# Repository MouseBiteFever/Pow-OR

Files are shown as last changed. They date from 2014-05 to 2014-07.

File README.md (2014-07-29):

Pow-OR
======

Power multiplexer

This will be a repository for the Eagle CAD design files of the Pow-OR power multiplexer board.
<br>To follow development of the board please go to http://MouseBiteFever.tumblr.com
<br><br>
A few video demonstrations of the Pow-OR board on can be foud on youtube at http://www.youtube.com/channel/UCmLNvzKj7SQ2D3ENkpwOFEA
<br><br>
I have put a small number of these up for sale on Tindie, and I just added 10 more as of 7/28/14. I'll be updating the stock as I get chips in and assemble boards.<br>
https://www.tindie.com/products/MouseBiteFever/pow-or-v131/
<br><br>

<br />This work is licensed under a <a rel="license" href="http://creativecommons.org/licenses/by-sa/4.0/">Creative Commons Attribution-ShareAlike 4.0 International License</a>.

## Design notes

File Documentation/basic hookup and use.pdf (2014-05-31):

## Pow-OR Basic Hookup and Usage Guide

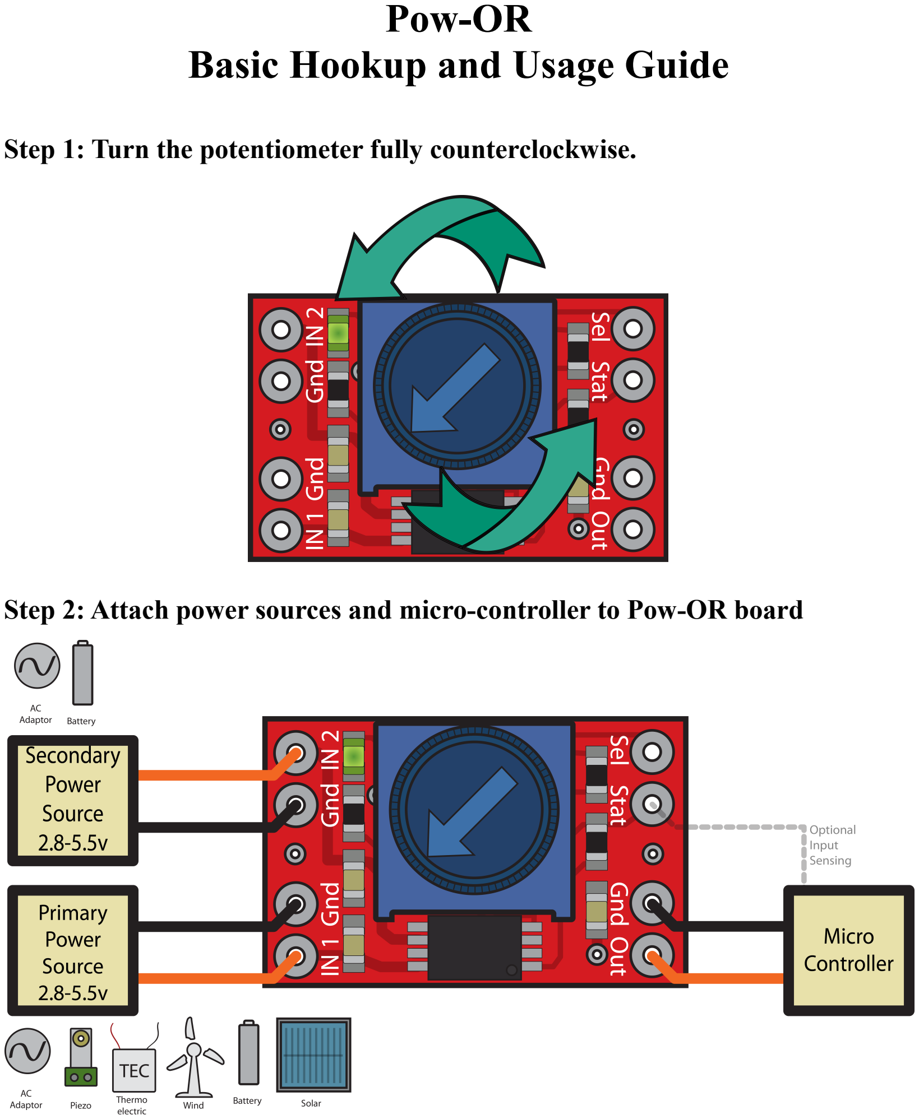
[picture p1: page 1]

Step 1: Turn the potentiometer fully counterclockwise.
Step 2: Attach power sources and micro-controller to Pow-OR board

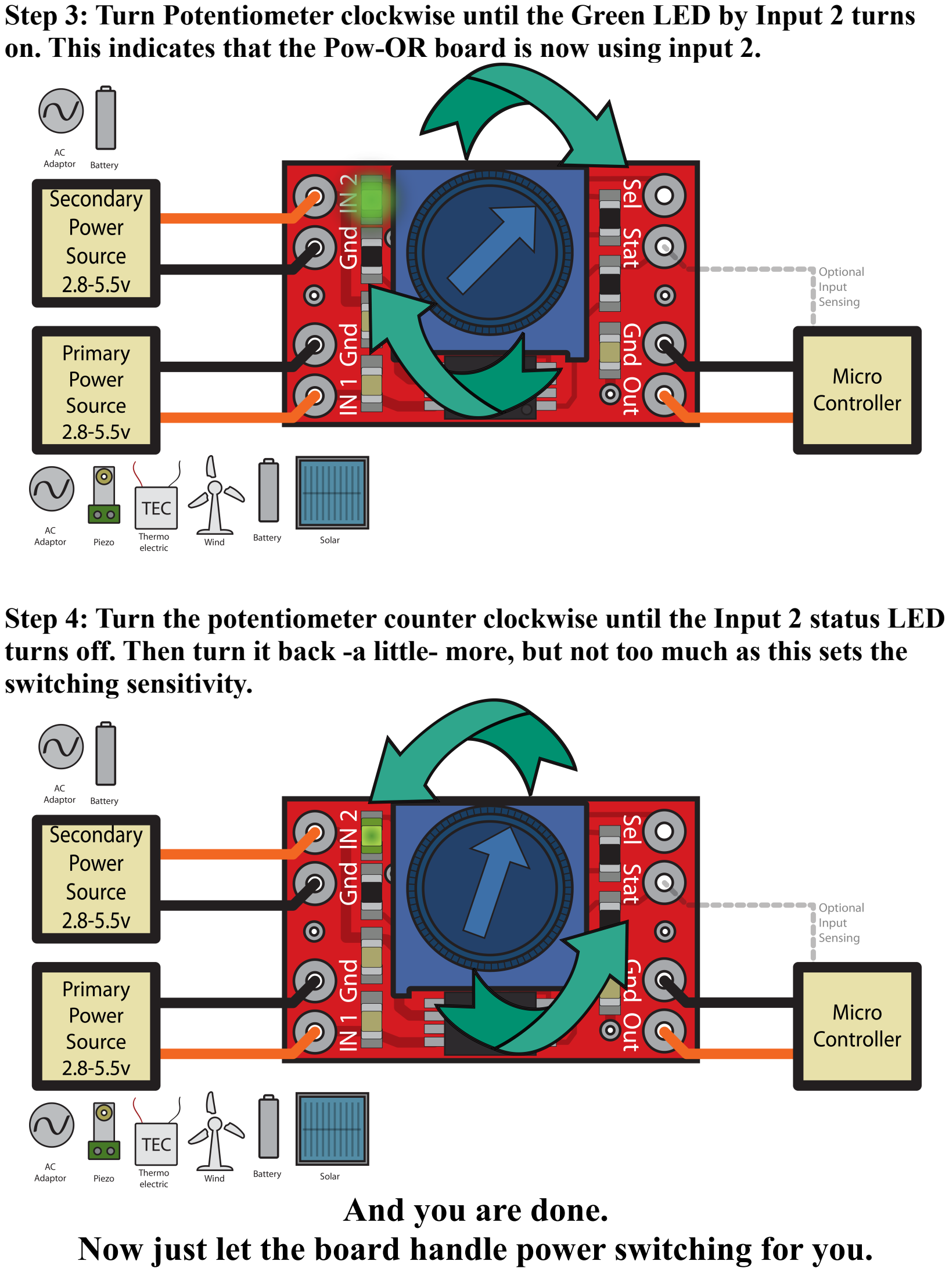
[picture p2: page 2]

Step 3: Turn Potentiometer clockwise until the Green LED by Input 2 turns on. This indicates that the Pow-OR board is now using input 2.
Step 4: Turn the potentiometer counter clockwise until the Input 2 status LED turns off. Then turn it back -a little- more, but not too much as this sets the switching sensitivity.

And you are done.
Now just let the board handle power switching for you.

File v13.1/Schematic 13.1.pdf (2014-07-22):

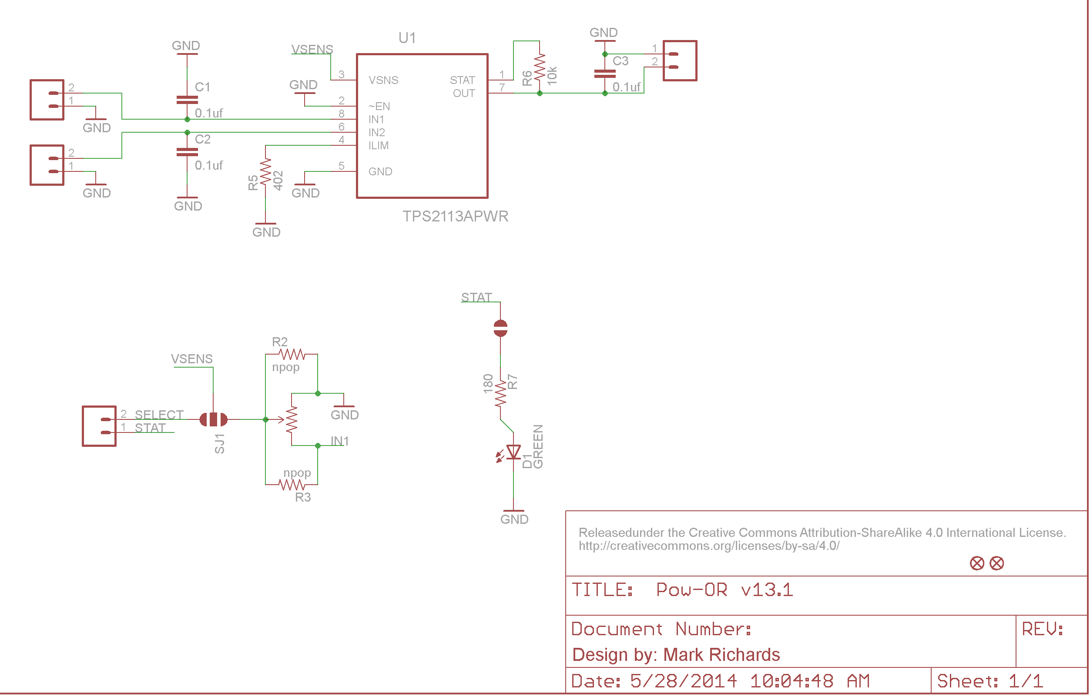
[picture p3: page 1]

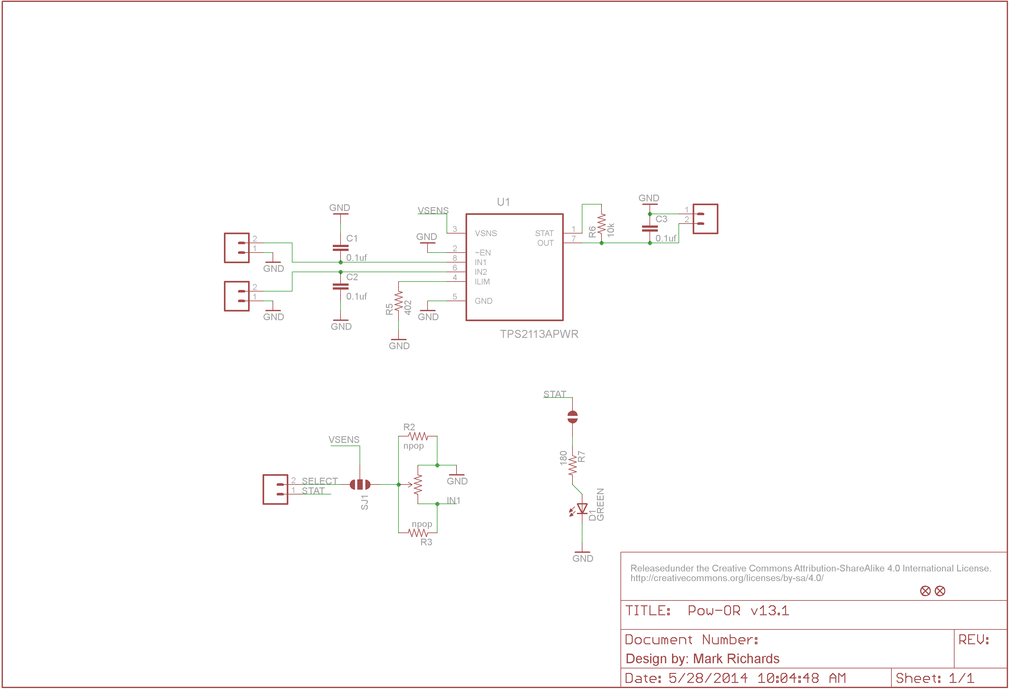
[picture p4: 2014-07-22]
v13.1/Schematic 13.1.png

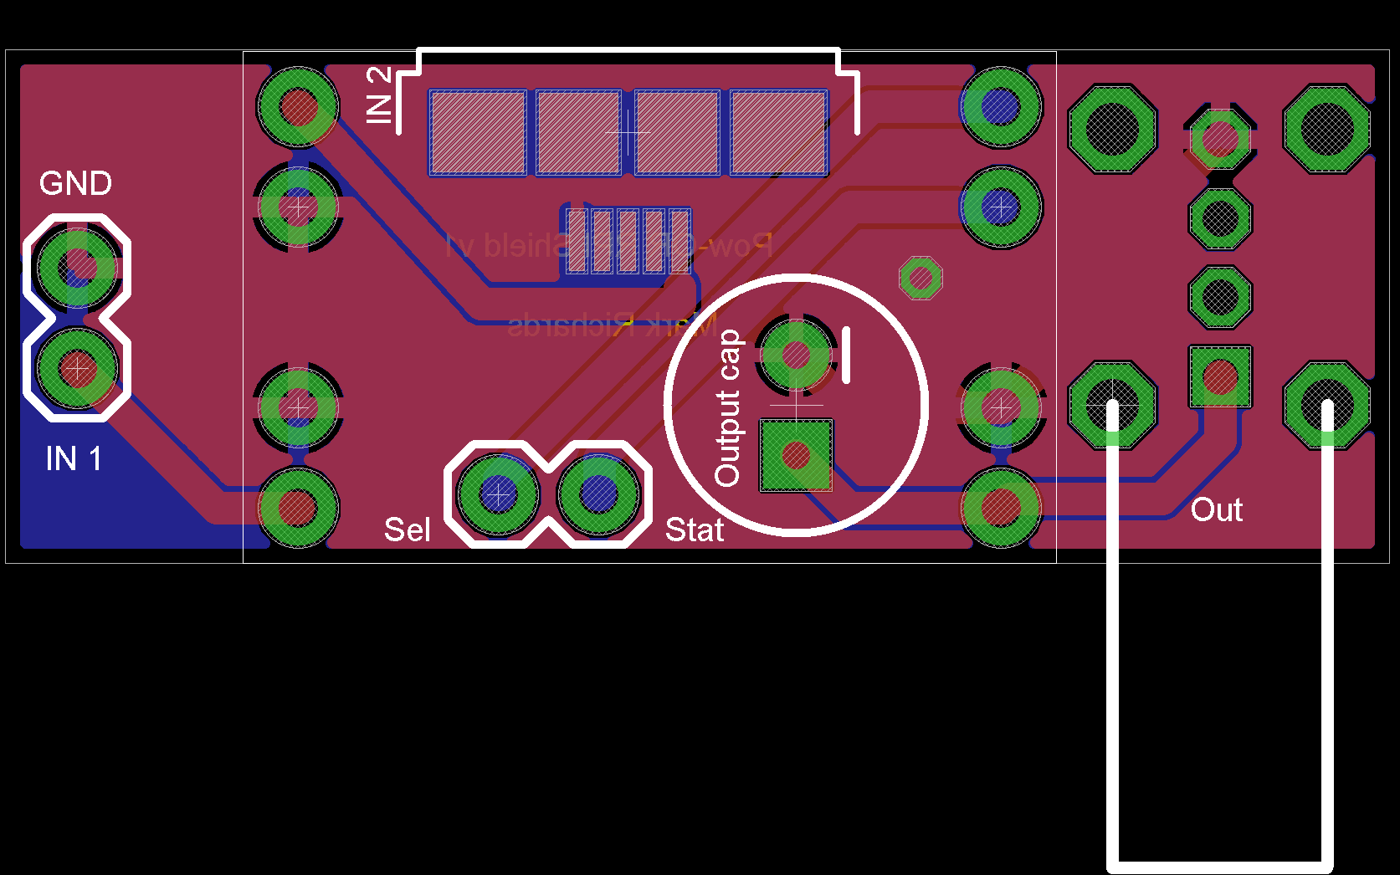
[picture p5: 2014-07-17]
RPI shield/v1.png

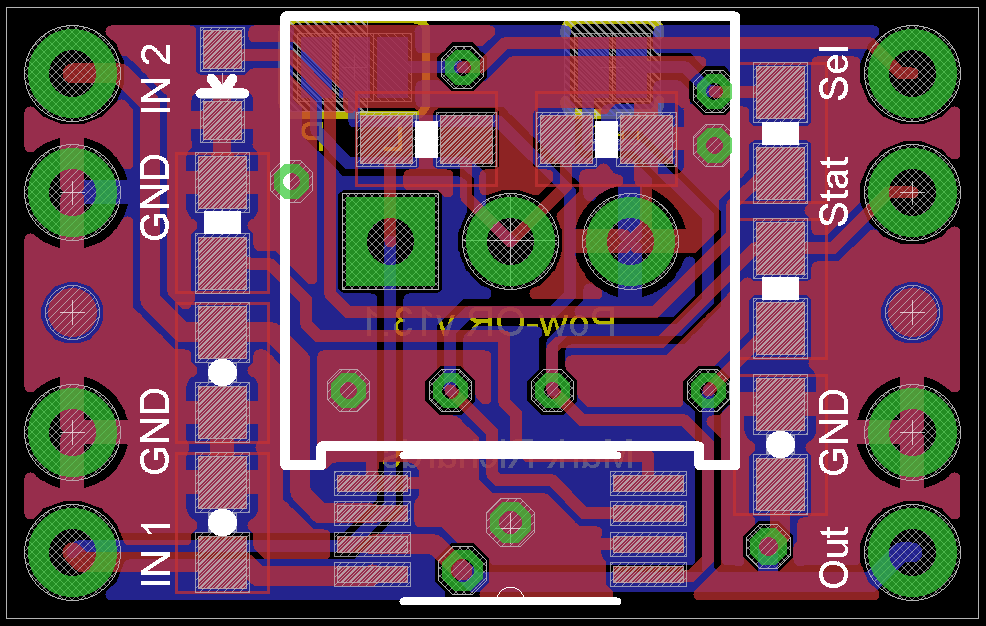
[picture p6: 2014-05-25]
v13.1/v13.1.png

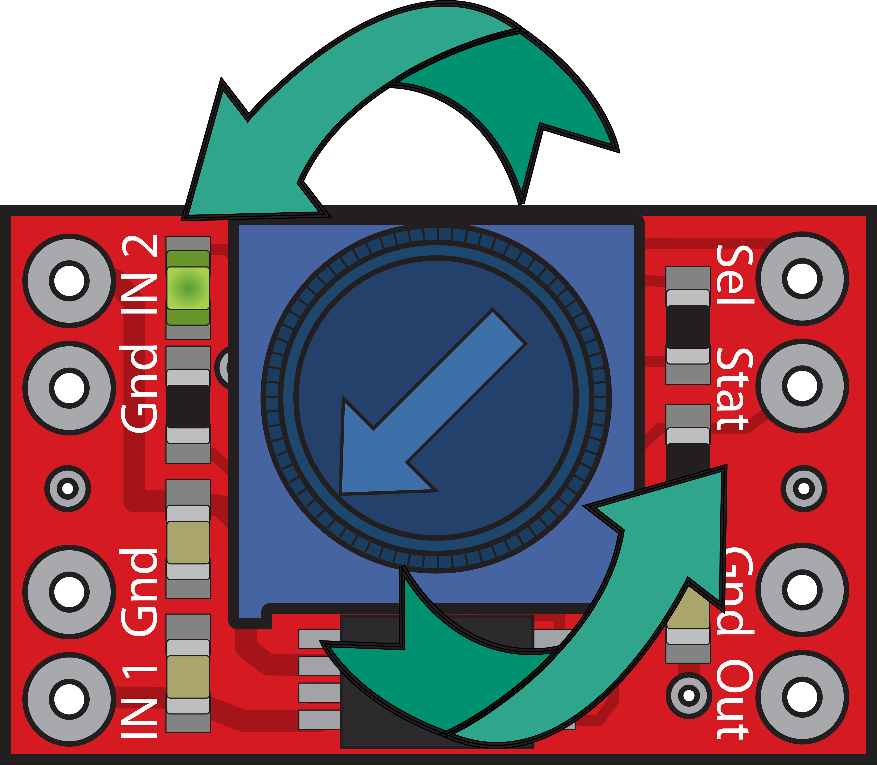
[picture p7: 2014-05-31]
Documentation/counterclockwise1.png

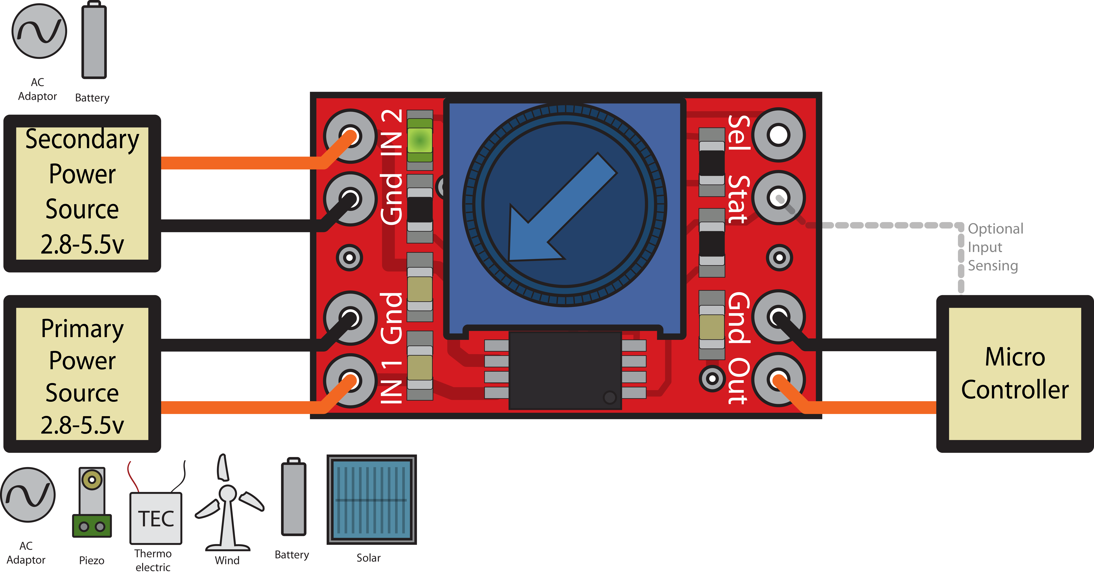
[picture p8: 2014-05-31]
Documentation/hookup.png

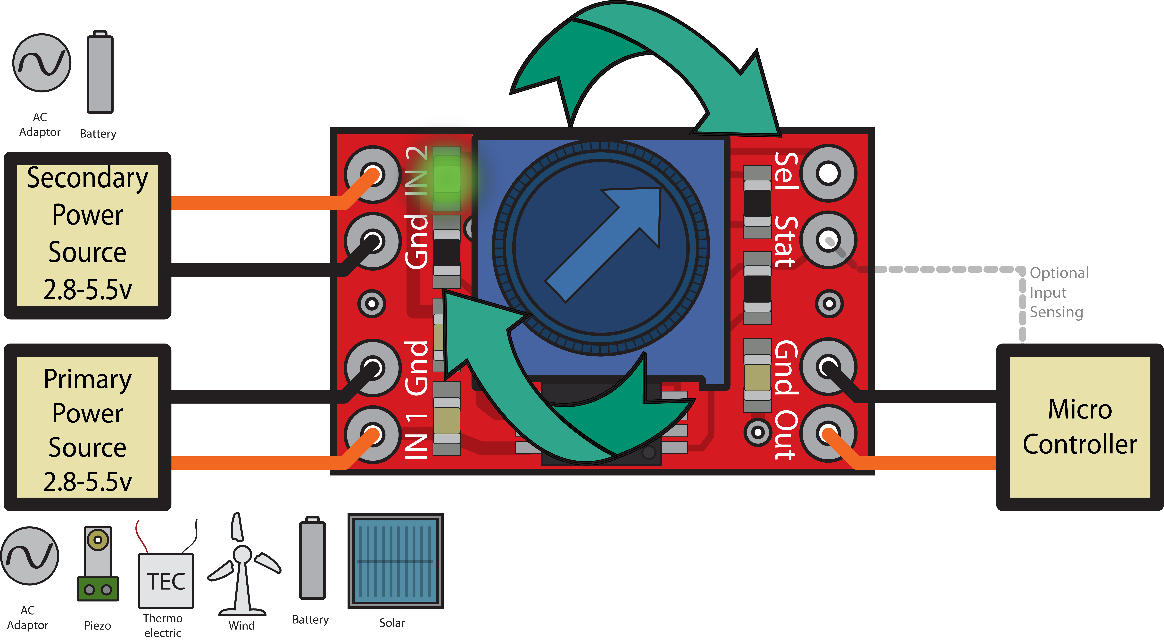
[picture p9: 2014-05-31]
Documentation/clockwise.png

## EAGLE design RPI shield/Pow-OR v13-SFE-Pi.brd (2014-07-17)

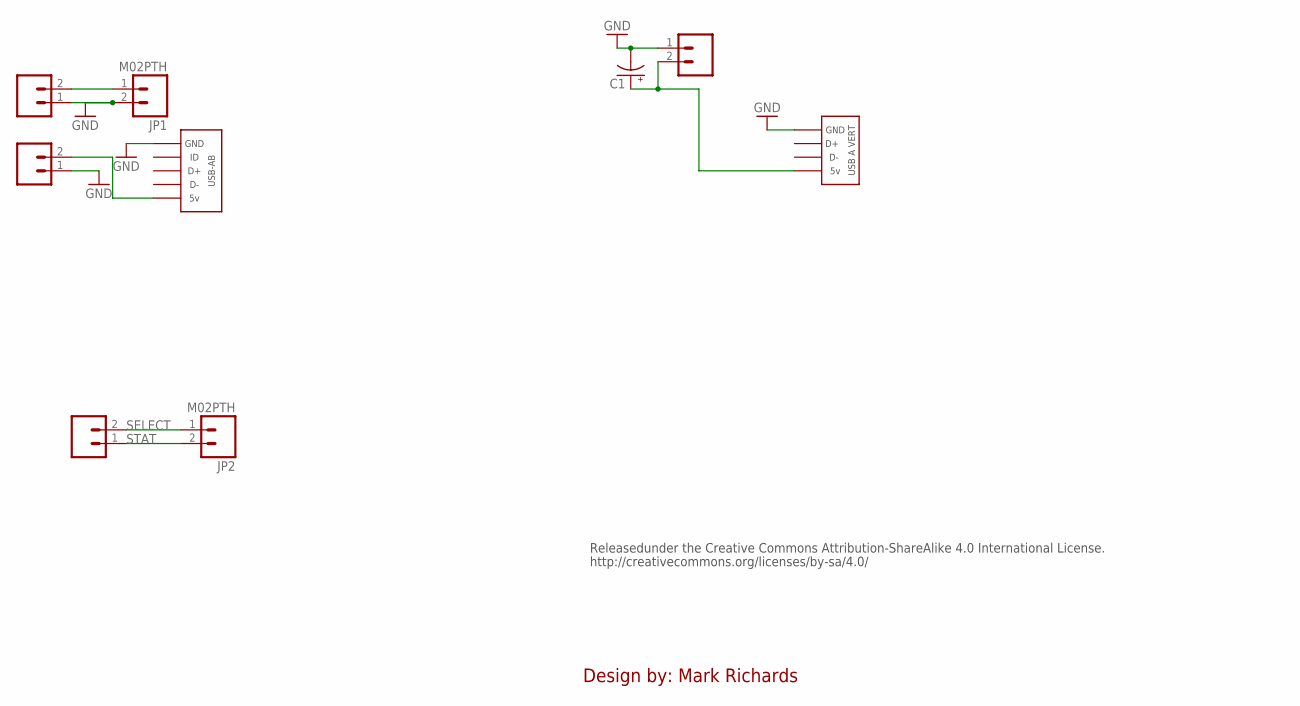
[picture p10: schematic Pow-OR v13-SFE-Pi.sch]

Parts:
C1: CAP_POLPTH1; CPOL-RADIAL-100UF-25V
JP1, JP2: M02PTH; 1X02
JP3, JP4, JP5, JP6: M021X02_NO_SILK; 1X02_NO_SILK
U$1: USB-AB
U$2: USBA-VERT

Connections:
GND: C1.2 (-), JP1.2, JP3.1, JP4.1, JP6.1, U$1.G, U$2.NEG (GND)
IN1: JP1.1, JP3.2
unnamed: JP4.2, U$1.V
OUT: C1.1 (+), JP6.2, U$2.VCC
SELECT: JP2.1, JP5.2
STAT: JP2.2, JP5.1

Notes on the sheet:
Releasedunder the Creative Commons Attribution-ShareAlike 4.0 International License.
http://creativecommons.org/licenses/by-sa/4.0/
Design by: Mark Richards

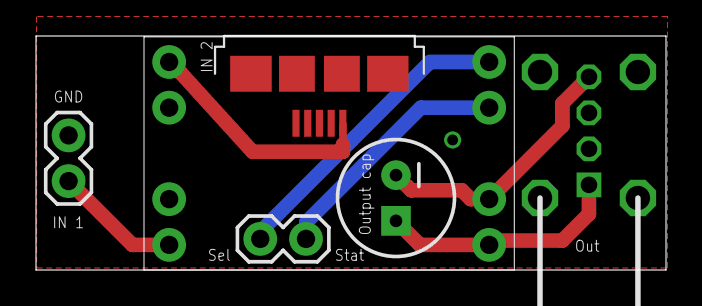
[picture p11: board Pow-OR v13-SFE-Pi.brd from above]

Board: 2 copper layers, 35.0 x 13.0 mm, 9 parts (0 on the bottom side), 6 nets.

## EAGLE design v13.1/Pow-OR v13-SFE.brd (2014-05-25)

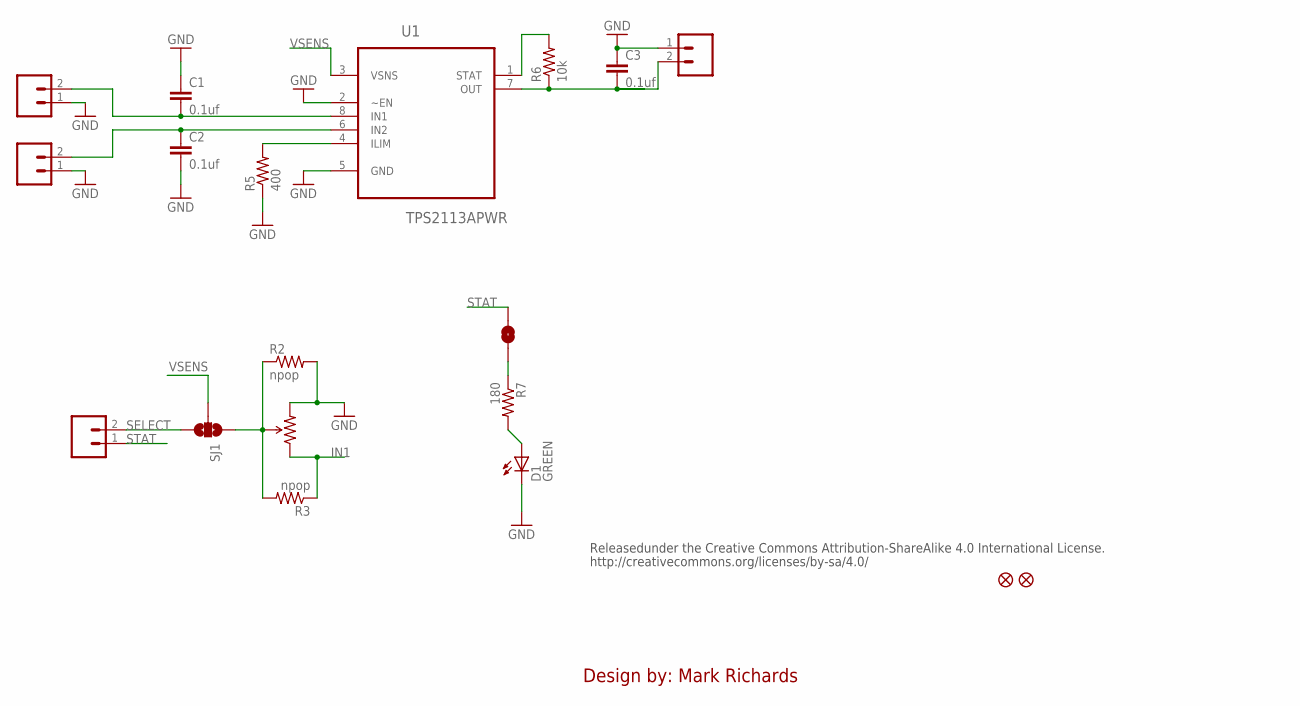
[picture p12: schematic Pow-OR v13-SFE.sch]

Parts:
C1, C2, C3: 0.1uf; 0603-CAP
D1: GREEN; LED-0603
FID1, FID2: FIDUCIAL1X2; FIDUCIAL-1X2
JP3, JP4, JP5, JP6: M021X02_NO_SILK; 1X02_NO_SILK
R1: TRIMPOT-PTH-KNOB; 3386U
R2, R3: npop; 0603-RES
R5: 400; 0603-RES
R6: 10k; 0603-RES
R7: 180; 0603-RES
SJ1: SOLDERJUMPER_2WAYPASTE1&2; SJ_3_PASTE1&2
SJ2: SOLDERJUMPERNC2; SJ_2S-NOTRACE
U1: TPS2113APWR; SOP65P640X120-8N

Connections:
GND: C1.1, C2.2, C3.1, D1.C, JP3.1, JP4.1, JP6.1, R1.3 (CW), R2.2, R5.1, U1.2 (~EN), U1.5 (GND)
ILIM: R5.2, U1.4 (ILIM)
IN1: C1.2, JP3.2, R1.1 (CCW), R3.1, U1.8 (IN1)
IN2: C2.1, JP4.2, U1.6 (IN2)
unnamed: D1.A, R7.2
unnamed: R1.2 (WIPER), R2.1, R3.2, SJ1.1
unnamed: R7.1, SJ2.1
OUT: C3.2, JP6.2, R6.1, U1.7 (OUT)
SELECT: JP5.2, SJ1.3
STAT: JP5.1, R6.2, SJ2.2, U1.1 (STAT)
VSENS: SJ1.2, U1.3 (VSNS)

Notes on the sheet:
Releasedunder the Creative Commons Attribution-ShareAlike 4.0 International License.
http://creativecommons.org/licenses/by-sa/4.0/
Design by: Mark Richards

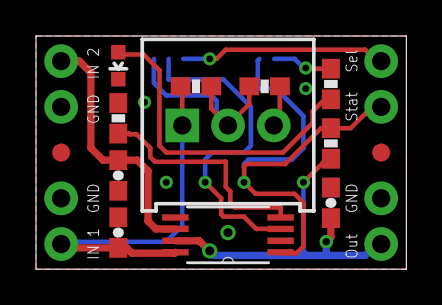
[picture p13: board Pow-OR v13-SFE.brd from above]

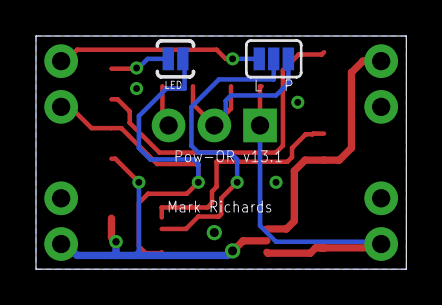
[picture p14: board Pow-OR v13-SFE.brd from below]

Board: 2 copper layers, 20.6 x 13.0 mm, 19 parts (2 on the bottom side), 11 nets.

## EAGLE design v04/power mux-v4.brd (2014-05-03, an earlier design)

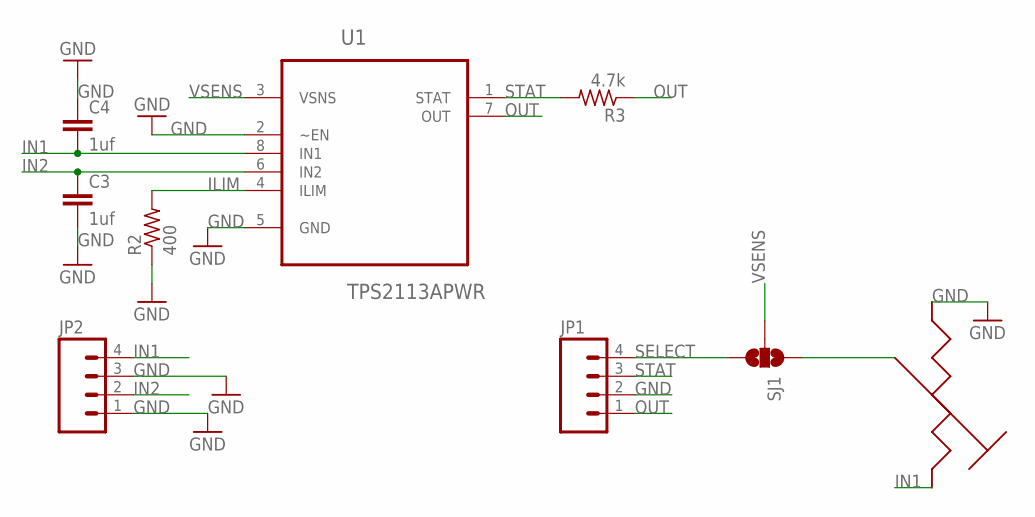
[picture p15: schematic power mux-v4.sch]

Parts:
C3, C4: 1uf; 0402-CAP
JP1, JP2: M04PTH; 1X04
R2: 400; R0402
R3: 4.7k; R0402
SJ1: SOLDERJUMPER_2WAYPASTE1&2; SJ_3_PASTE1&2
U1: TPS2113APWR; SOP65P640X120-8N
U$2: TRIMPOT-10K

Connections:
GND: C3.2, C4.1, JP1.2, JP2.1, JP2.3, R2.1, U1.2 (~EN), U1.5 (GND), U$2.1 (IN)
ILIM: R2.2, U1.4 (ILIM)
IN1: C4.2, JP2.4, U1.8 (IN1), U$2.2 (OUT)
IN2: C3.1, JP2.2, U1.6 (IN2)
unnamed: SJ1.1, U$2.3 (W)
OUT: JP1.1, R3.1, U1.7 (OUT)
SELECT: JP1.4, SJ1.3
STAT: JP1.3, R3.2, U1.1 (STAT)
VSENS: SJ1.2, U1.3 (VSNS)

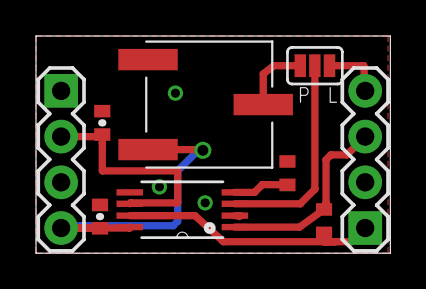
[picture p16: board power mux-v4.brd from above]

Board: 2 copper layers, 19.7 x 12.1 mm, 9 parts (0 on the bottom side), 9 nets.

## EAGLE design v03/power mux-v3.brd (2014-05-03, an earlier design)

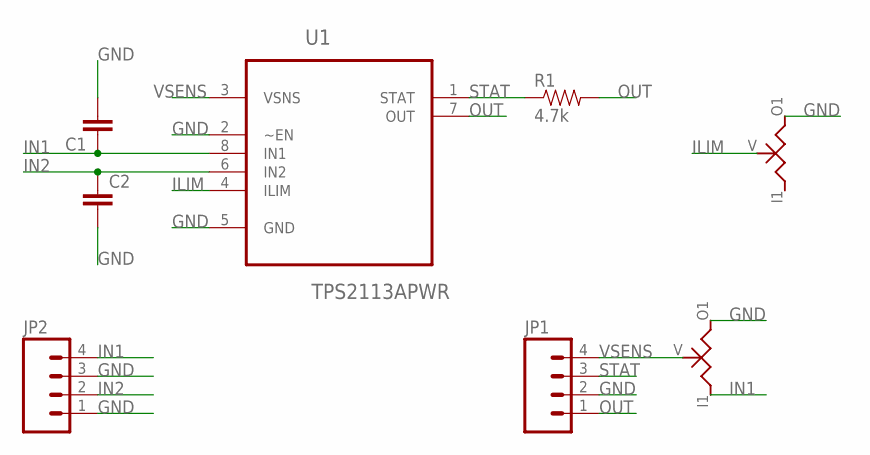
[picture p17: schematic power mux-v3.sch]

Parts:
C1, C2: CAP0805; 0805
JP1, JP2: M04PTH; 1X04
R1: 4.7k; 0805
U1: TPS2113APWR; SOP65P640X120-8N
U$1, U$2: TC33X-2

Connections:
GND: C1.2, C2.2, JP1.2, JP2.1, JP2.3, U1.2 (~EN), U1.5 (GND), U$1.O1 (OUT), U$2.O1 (OUT)
ILIM: U1.4 (ILIM), U$2.V (VAR)
IN1: C1.1, JP2.4, U1.8 (IN1), U$1.I1 (IN)
IN2: C2.1, JP2.2, U1.6 (IN2)
OUT: JP1.1, R1.2, U1.7 (OUT)
STAT: JP1.3, R1.1, U1.1 (STAT)
VSENS: JP1.4, U1.3 (VSNS), U$1.V (VAR)

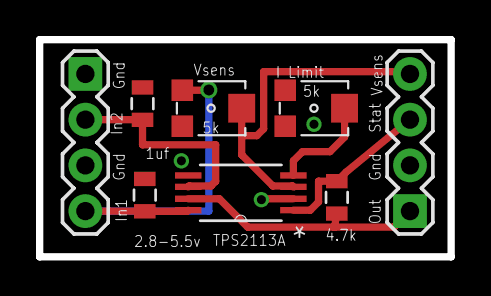
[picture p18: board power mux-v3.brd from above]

Board: 2 copper layers, 22.9 x 12.1 mm, 8 parts (0 on the bottom side), 7 nets.

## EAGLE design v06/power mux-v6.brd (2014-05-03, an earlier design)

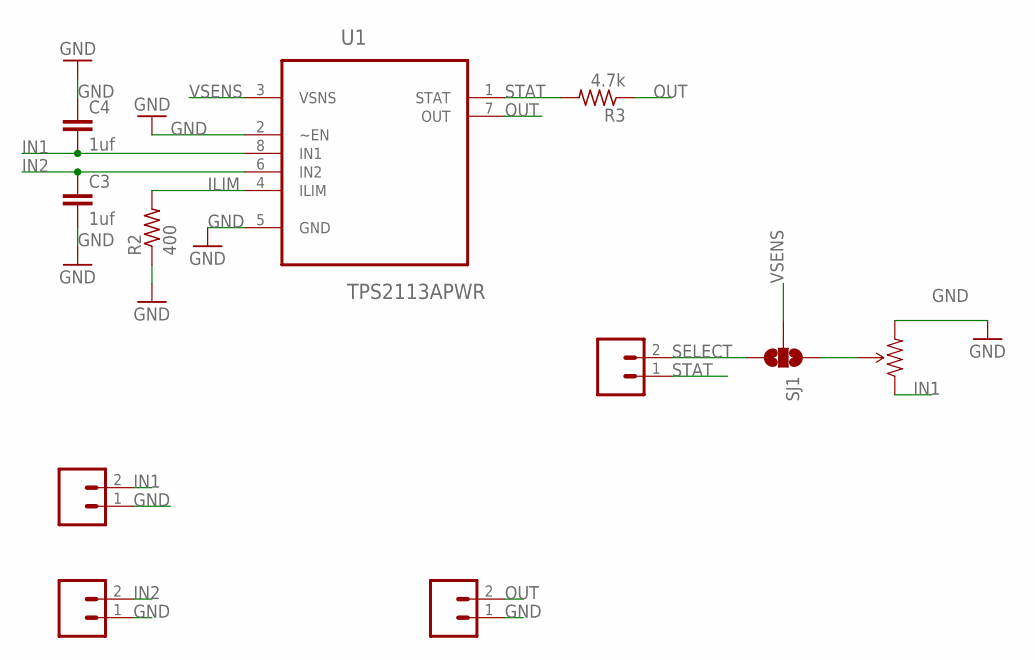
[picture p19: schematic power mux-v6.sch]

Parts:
C3, C4: 1uf; 0402-CAP
JP3, JP4, JP5, JP6: M021X02_NO_SILK; 1X02_NO_SILK
R1: TRIMPOT-PTH-KNOB; 3386U
R2: 400; R0402
R3: 4.7k; R0402
SJ1: SOLDERJUMPER_2WAYPASTE1&2; SJ_3_PASTE1&2
U1: TPS2113APWR; SOP65P640X120-8N

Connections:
GND: C3.2, C4.1, JP3.1, JP4.1, JP6.1, R1.3 (CW), R2.1, U1.2 (~EN), U1.5 (GND)
ILIM: R2.2, U1.4 (ILIM)
IN1: C4.2, JP3.2, R1.1 (CCW), U1.8 (IN1)
IN2: C3.1, JP4.2, U1.6 (IN2)
unnamed: R1.2 (WIPER), SJ1.1
OUT: JP6.2, R3.1, U1.7 (OUT)
SELECT: JP5.2, SJ1.3
STAT: JP5.1, R3.2, U1.1 (STAT)
VSENS: SJ1.2, U1.3 (VSNS)

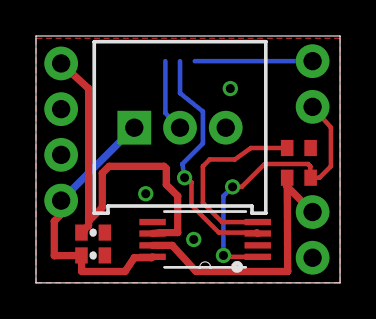
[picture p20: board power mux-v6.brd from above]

Board: 2 copper layers, 16.9 x 13.7 mm, 11 parts (1 on the bottom side), 9 nets.

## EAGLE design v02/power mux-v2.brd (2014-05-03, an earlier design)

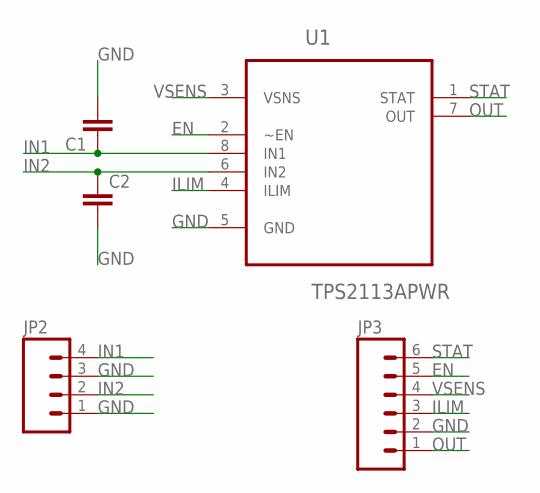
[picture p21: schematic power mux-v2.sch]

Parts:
C1, C2: CAP0805; 0805
JP2: M04PTH; 1X04
JP3: M06SIP; 1X06
U1: TPS2113APWR; SOP65P640X120-8N

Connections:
EN: JP3.5, U1.2 (~EN)
GND: C1.2, C2.2, JP2.1, JP2.3, JP3.2, U1.5 (GND)
ILIM: JP3.3, U1.4 (ILIM)
IN1: C1.1, JP2.4, U1.8 (IN1)
IN2: C2.1, JP2.2, U1.6 (IN2)
OUT: JP3.1, U1.7 (OUT)
STAT: JP3.6, U1.1 (STAT)
VSENS: JP3.4, U1.3 (VSNS)


Board: 2 copper layers, 17.8 x 19.1 mm, 5 parts (0 on the bottom side), 8 nets.

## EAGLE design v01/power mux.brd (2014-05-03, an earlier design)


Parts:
C1, C2: CAP0805; 0805
H1, H2: MOUNT-PAD-ROUND3.0; 3,0-PAD
JP1, JP2, JP4: M025MM; SCREWTERMINAL-5MM-2
R1, R2, R3, R4: RESISTORPTH-1/4W-VERT; AXIAL-0.1
U1: TPS2113APWR; SOP65P640X120-8N

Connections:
GND: C1.2, C2.2, JP1.2, JP2.2, JP4.2, U1.5 (GND)
GND6: R2.P$1 (1), R3.P$1 (1), U1.2 (~EN)
ILIM: R3.P$2 (2), U1.4 (ILIM)
IN1+: C1.1, JP2.1, R1.P$2 (2), U1.8 (IN1)
IN2+: C2.1, JP4.1, U1.6 (IN2)
unnamed: R4.P$2 (2), U1.1 (STAT)
OUT: JP1.1, R4.P$1 (1), U1.7 (OUT)
VSENS: R1.P$1 (1), R2.P$2 (2), U1.3 (VSNS)

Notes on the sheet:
output
input2
input1
22ohm
10ohm
3.3v
1.03v


Board: 2 copper layers, 25.1 x 25.3 mm, 12 parts (0 on the bottom side), 8 nets.

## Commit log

2014-05-03 Eagle CAD design files
    All versions to date.
    [power mux-fpf1320.brd, power mux-fpf1320.sch, power mux-v10.brd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]
2014-05-03 Board Images
    Added images of all the boards.
    [power mux-v10.brd, power mux-v11.brd, power mux-v12.brd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]
2014-05-03 Reorganization
    Pulled all files out of the pow-or folder
    [power mux-fpf1320.brd, power mux-fpf1320.sch, power mux-v10.brd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]
2014-05-03 Folder Renaming
    constant naming scheme
    [power mux-v2.brd, power mux-v2.sch, power mux-v3.brd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]
2014-05-25 Minor changes
    cleaned up schematic, added fiducials, etc
    [Pow-OR v13-SFE.brd, Pow-OR v13-SFE.sch]
2014-05-31 Updated Documentation
    added volt ranges, remade pdf
2014-07-17 Added Raspberry Pi Shield
    Added V1
    [Pow-OR v13-SFE-Pi.brd, Pow-OR v13-SFE-Pi.sch]
2014-07-22 Schematics
    schematics for v13.1
2014-07-23 schematics
    duplicating the sch pdf in the v13.1 folder

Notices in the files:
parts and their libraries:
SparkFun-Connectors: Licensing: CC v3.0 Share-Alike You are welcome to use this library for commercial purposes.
